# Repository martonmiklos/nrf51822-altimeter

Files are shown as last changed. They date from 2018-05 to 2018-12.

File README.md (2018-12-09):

# nrf51822-altimeter
nRF51822 based altimeter board for model rockets

A small module built around a [WT51822-S4AT](https://www.tme.eu/hu/details/wt51822-s4at/iot-wifibluetooth-modulok/wireless-tag) BLE module.

Features a DPS310 barometer and an MMA8452Q accelerometer. 

Firmware code lives here:

https://github.com/martonmiklos/nrf51822-altimeter-fw

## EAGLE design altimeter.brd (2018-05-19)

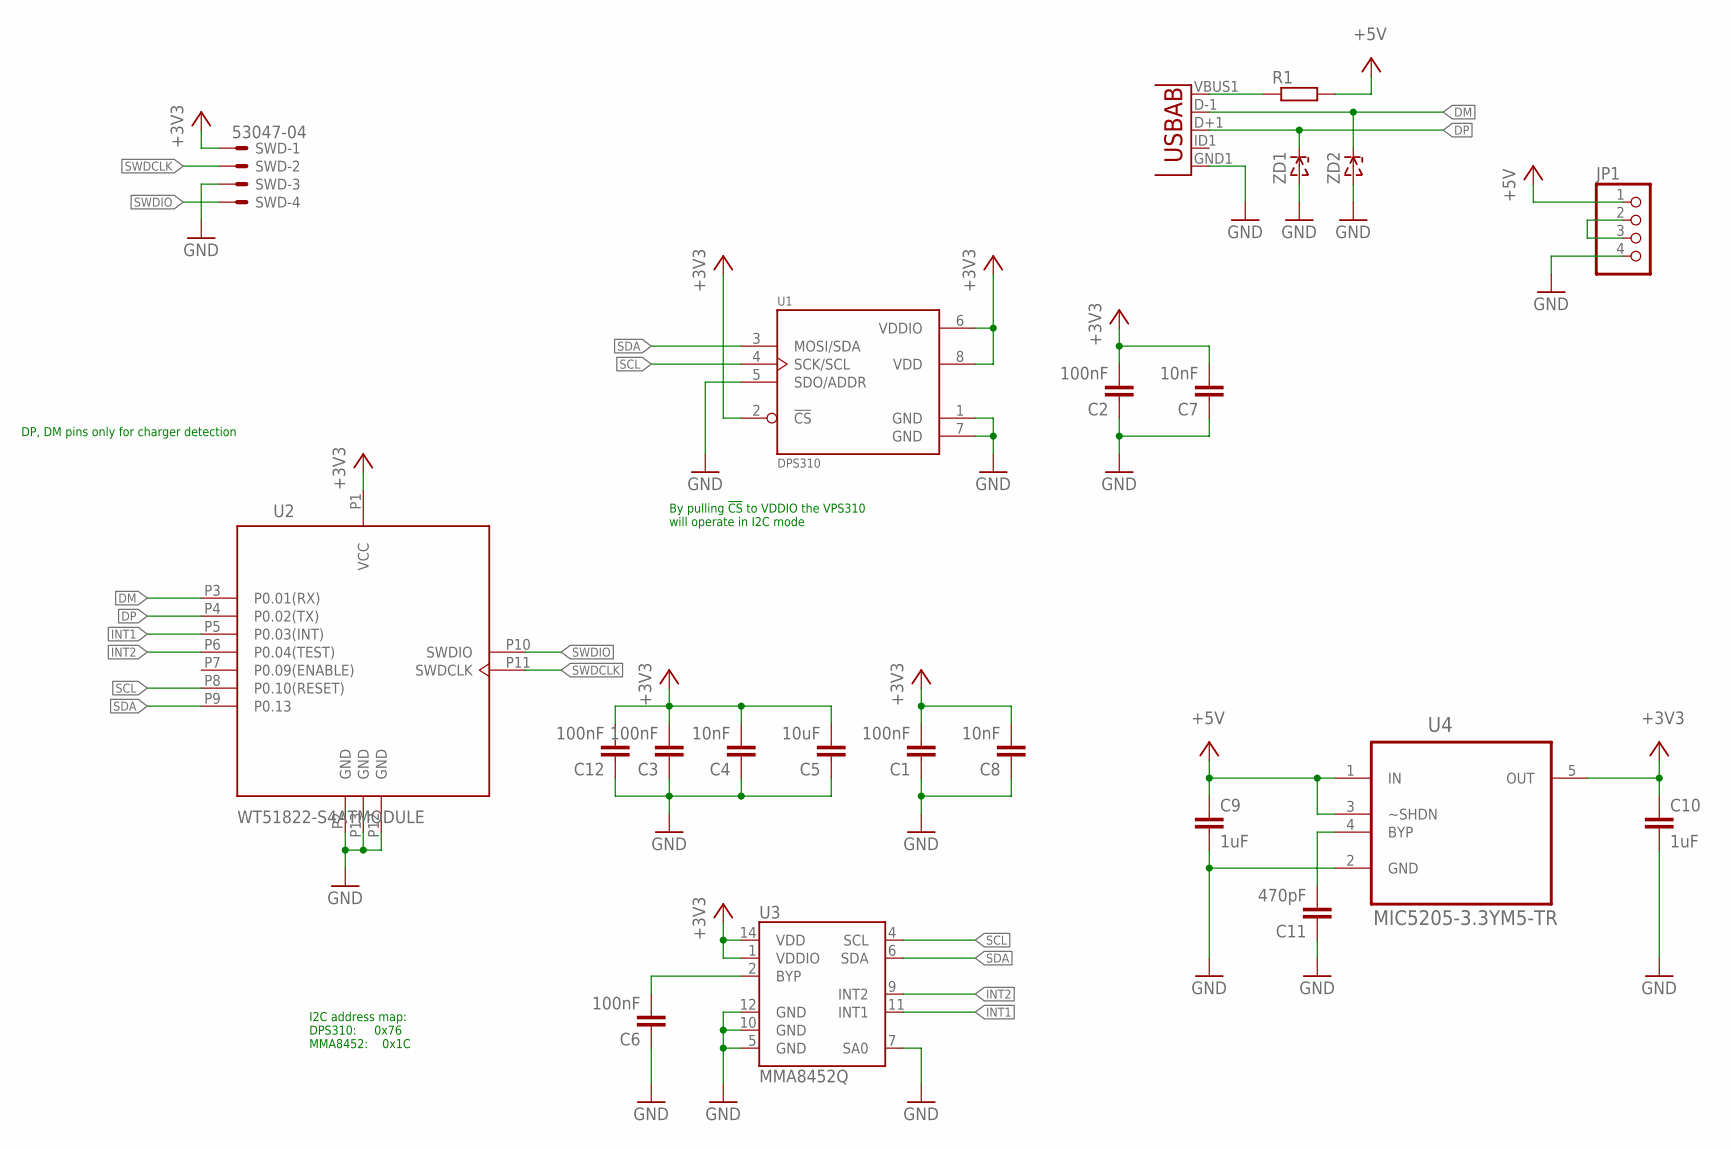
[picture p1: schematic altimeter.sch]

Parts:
C1, C2, C3, C6, C12: 100nF; C0603
C4, C7, C8: 10nF; C0603
C5: 10uF; C0805
C9, C10: 1uF; C0603
C11: 470pF; C0603
JP1: PINHD-1X4; 1X04
R1: R-EU_R0805; R0805
SWD: 53047-04
U1: DPS310; LGA8S145X65P2X4_200X250X100
U2: WT51822-S4ATMODULE; WT51822-S4AT
U3: MMA8452Q; QFN-16_0.5MM
U4: MIC5205-3.3YM5-TR; SOT95P280X145-5N
USB: USB-ABIN&OUT; USB-AB-MICRO-SMD-V03-IN&OUT
ZD1, ZD2: ZENERSOD-123; SOD-123

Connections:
+3V3: C1.2, C2.2, C3.2, C4.2, C5.2, C7.2, C8.2, C10.1, C12.2, SWD.1, U1.2 (!CS), U1.6 (VDDIO), U1.8 (VDD), U2.P1 (VCC), U3.1 (VDDIO), U3.14 (VDD), U4.5 (OUT)
+5V: C9.1, JP1.1, R1.2, U4.1 (IN), U4.3 (~SHDN)
DM: U2.P3 (P0.01(RX)), USB.D-1 (D-), ZD2.C
DP: U2.P4 (P0.02(TX)), USB.D+1 (D+), ZD1.C
GND: C1.1, C2.1, C3.1, C4.1, C5.1, C6.1, C7.1, C8.1, C9.2, C10.2, C11.1, C12.1, JP1.4, SWD.3, U1.1 (GND), U1.5 (SDO/ADDR), U1.7 (GND), U2.P2 (GND), U2.P12 (GND), U2.P13 (GND), U3.5 (GND), U3.7 (SA0), U3.10 (GND), U3.12 (GND), U4.2 (GND), USB.GND1 (GND), ZD1.A, ZD2.A
INT1: U2.P5 (P0.03(INT)), U3.11 (INT1)
INT2: U2.P6 (P0.04(TEST)), U3.9 (INT2)
unnamed: R1.1, USB.VBUS1 (VBUS)
unnamed: C6.2, U3.2 (BYP)
unnamed: JP1.2, JP1.3
unnamed: C11.2, U4.4 (BYP)
SCL: U1.4 (SCK/SCL), U2.P8 (P0.10(RESET)), U3.4 (SCL)
SDA: U1.3 (MOSI/SDA), U2.P9 (P0.13), U3.6 (SDA)
SWDCLK: SWD.2, U2.P11 (SWDCLK)
SWDIO: SWD.4, U2.P10 (SWDIO)

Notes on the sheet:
By pulling !CS! to VDDIO the VPS310 will operate in I2C mode
I2C address map: DPS310: 0x76 MMA8452: 0x1C
DP, DM pins only for charger detection

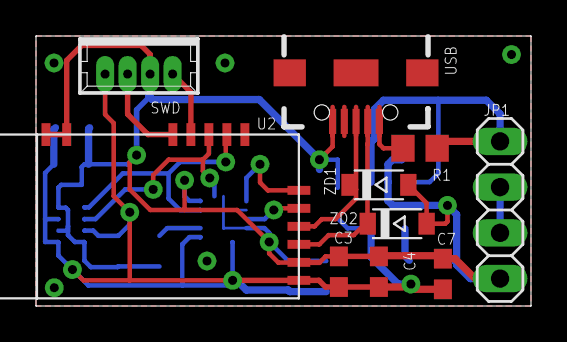
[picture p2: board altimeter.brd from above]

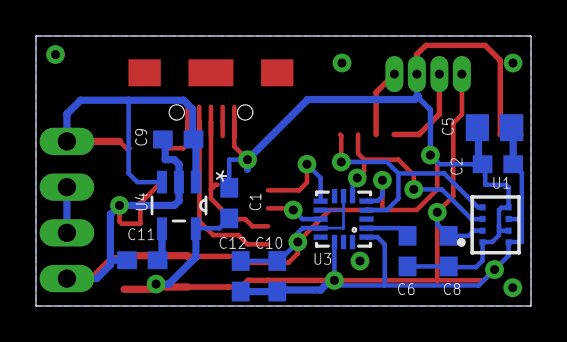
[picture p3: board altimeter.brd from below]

Board: 2 copper layers, 27.5 x 15.0 mm, 22 parts (12 on the bottom side), 15 nets.

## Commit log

2017-10-03 Initial add.
    [altimeter.brd, altimeter.sch]
2017-10-12 Silkscreen cleanup before gerber export.
    [altimeter.brd, altimeter.sch]
2018-05-19 Reorganized SCH
    [altimeter.brd]

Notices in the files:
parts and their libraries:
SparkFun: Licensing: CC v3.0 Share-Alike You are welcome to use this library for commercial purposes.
